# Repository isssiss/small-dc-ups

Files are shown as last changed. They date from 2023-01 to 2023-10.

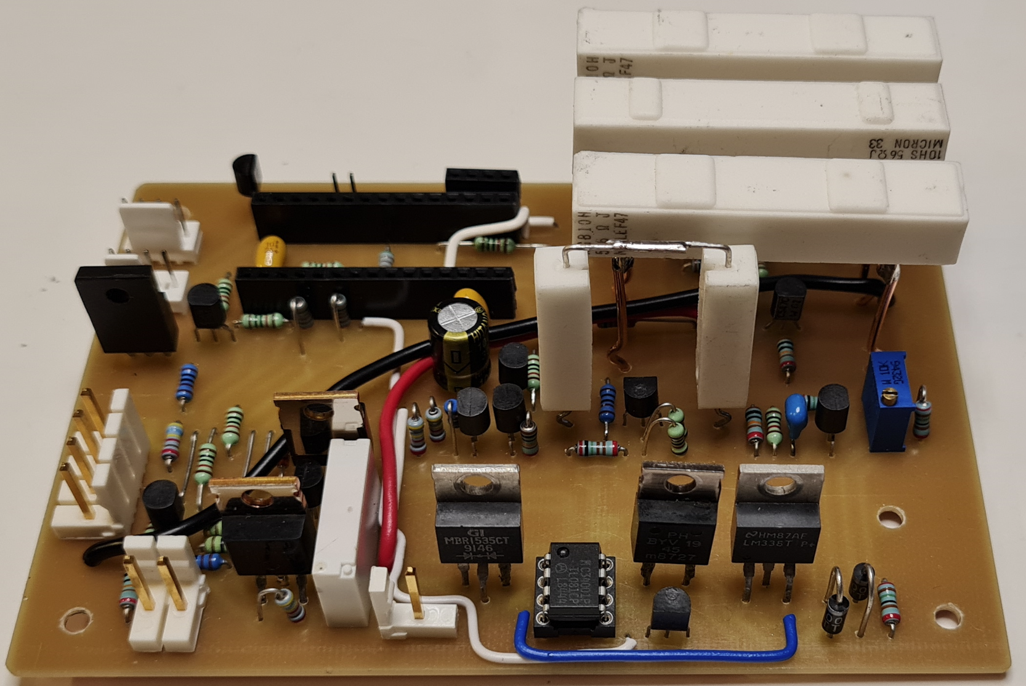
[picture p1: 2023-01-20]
controller/components.png

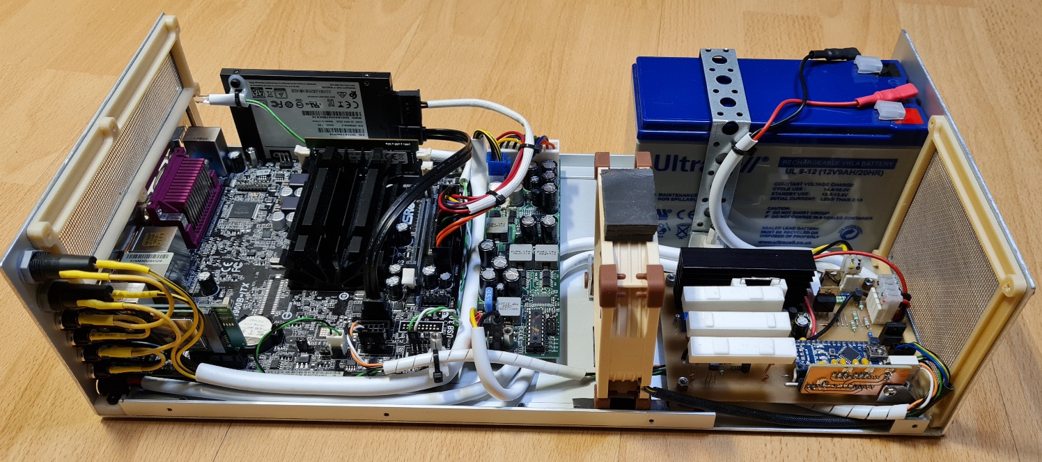
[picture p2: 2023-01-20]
finished.jpg

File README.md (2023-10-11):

# Small DC UPS for Home Assistant/Frigatenvr project

This is designed to power Asrock J1900M-ITX board with a PicoPSU automotive power supply with an input voltage 8...36V.
Mains power is provided by a laptop power supply with 19.5V output.

Backup battery is a 12V 9Ah lead acid gel battery (Ultracell UL-9-12).

Charger is a traditional standby current and voltage limited linear model.

Can be used with standard Network UPS Tools (NUT) with a blazer_ser driver and Megatec ascii protocol.

NOTE: I made only one pcb and the first version had an error. The error is corrected only in the schematic and v2 pcb image.

### Warning:

The output switch IRF9530 burned after a few months in use. Both IRF9530 were changed to IRF4905 which has much lower internal resistance and higher current rating. Zener diodes were also added in parallel of every fets 47k pullup resistor to limit the gate voltage to about 13V (2x 6.2V zeners in series).

Arduino LM340 voltage regulator is changed to a TSR 1-2540 dc converter because the original will run quite warm with 20V input.

Probably still contains errors and bugs.

I'm not responsible of any possible damage caused by any content stored here.

Use at your own risk, you have been warned.

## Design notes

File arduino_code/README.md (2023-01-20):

# Small-dc-ups Arduino code

I used an Arduino nano 5V 16MHz Atmega328P card.

* dc_ups.ino

  Main program

* ups_adc.h, ups_adc.cpp
    
  ADC helper code

* ups_util.h, ups_util.cpp

  Number formatting helpers

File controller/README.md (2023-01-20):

# Small DC UPS controller

UPS controller board

There are some old and various components because I designed this with the components I already had.

NOTE: Only one board was made and the schematic had an error. Fix can be seen in copper_side.png and it is fixed only in the schematic and pcb_v2_from_top.png.
Some components need to be installed on copper side.

In pcb_v2_from_top.png red lines are on pcb copper side, grey is ground (plane on copper side after milling the traces) and blue is  jumpers (board component side).

* ups_1_4_source.pdf

  Power connections and output current measurement.
  Use low dropout diode for D1 (MBR1535CT).

* ups_2_4_charge.pdf

  Battery charger and charge current measurement.
  Charge current can be adjusted with R17/R18.
  Adjust R23 to correct charge end voltage without a connected battery. Measure at D8 cathode.
  See components.png for R14-R15 placement.

* ups_3_4_control.pdf

  Arduino and fan control.

* ups_4_4_testload.pdf

  Battery test load.
  See components.png for R47-R49 placement.

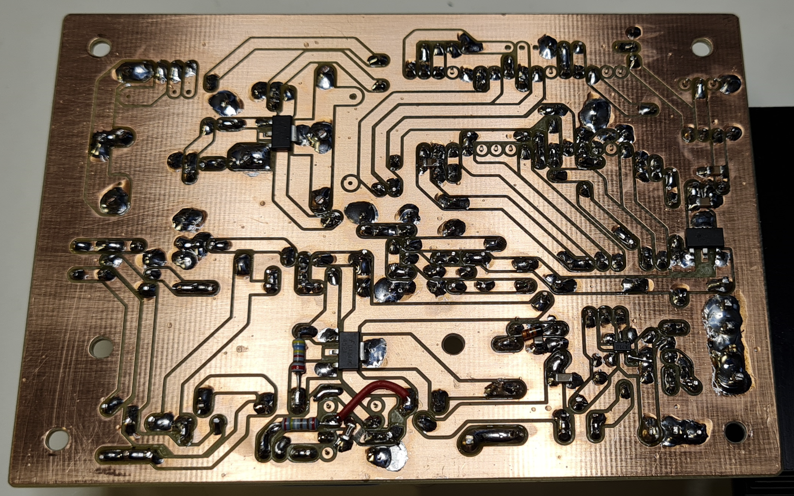
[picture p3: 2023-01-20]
controller/copper_side.png

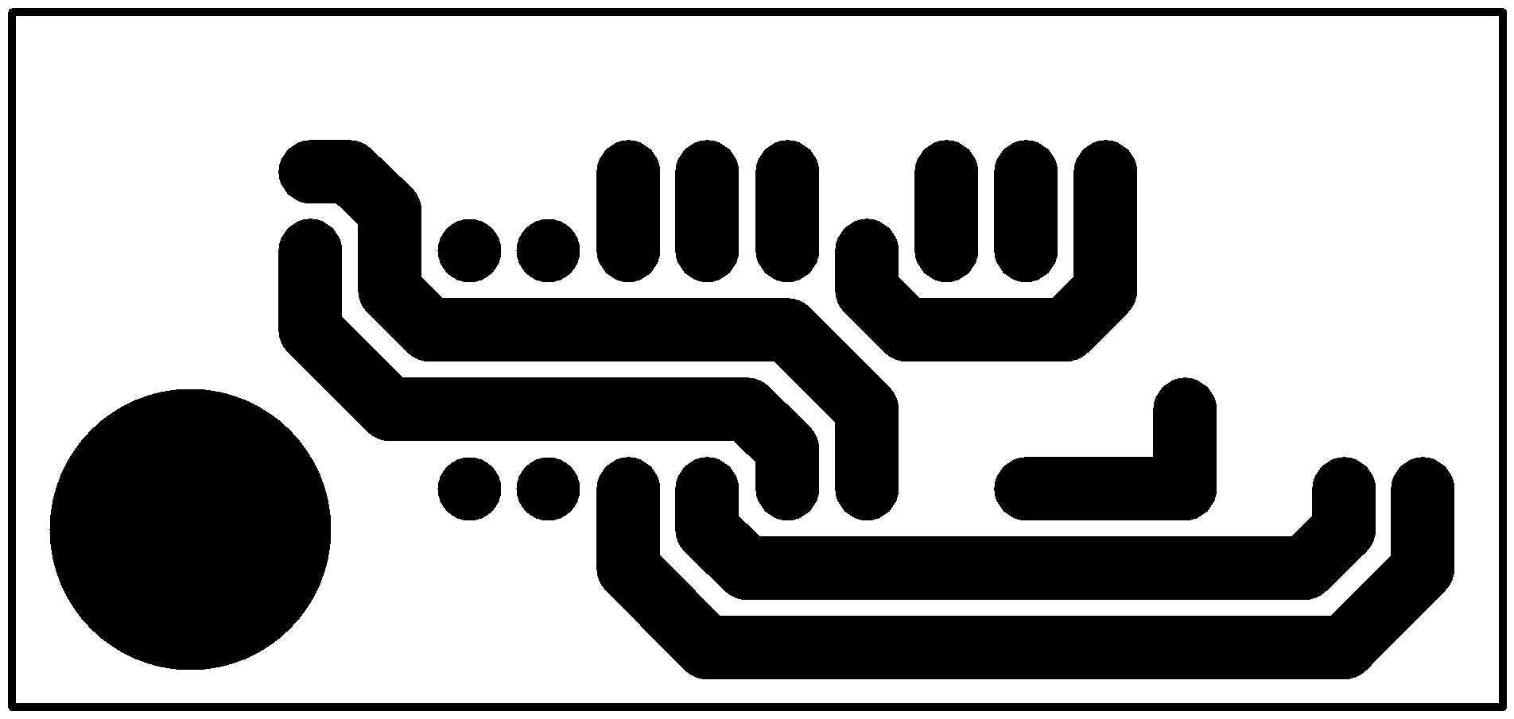
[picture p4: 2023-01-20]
serial/pcb files/SERIAL.BOTTOM.bmp

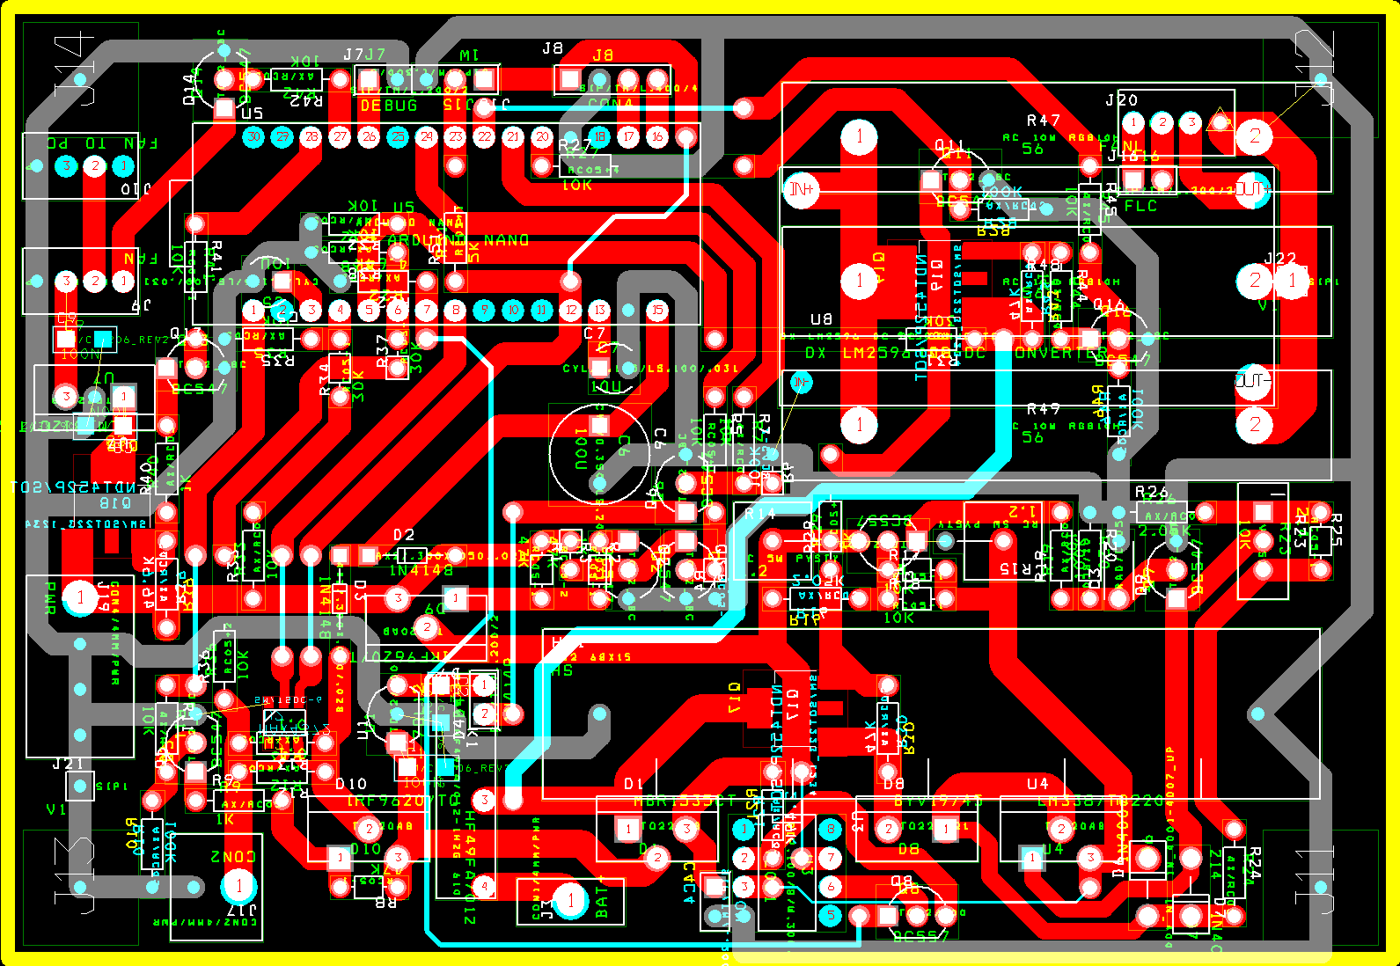
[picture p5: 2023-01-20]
controller/pcb_v2_from_top.png

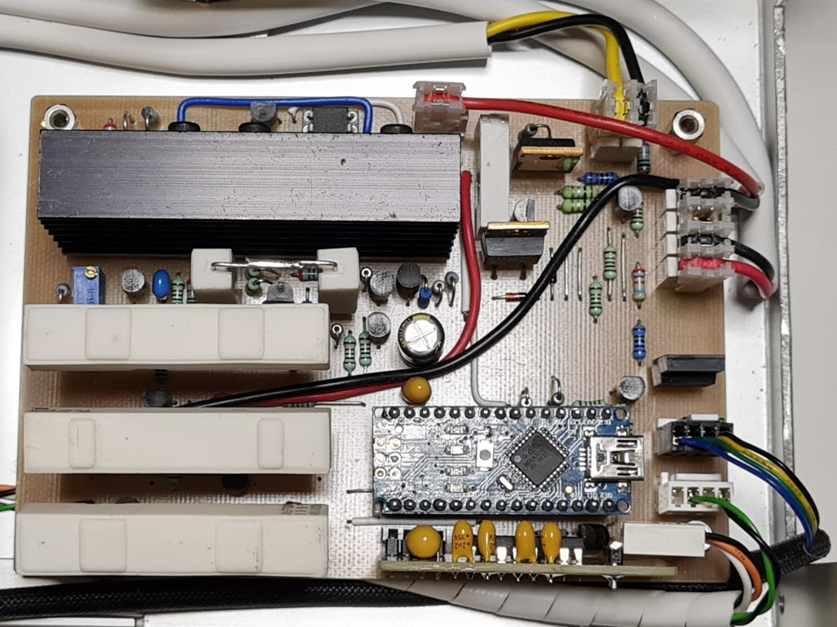
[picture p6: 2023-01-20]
controller/finished.png

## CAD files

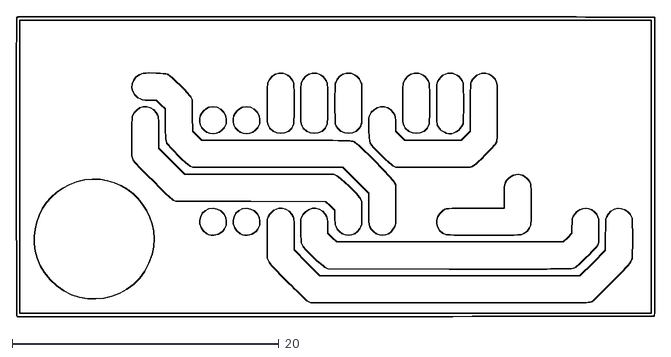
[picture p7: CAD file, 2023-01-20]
serial/pcb files/SERIAL.BOTTOM.dxf
47.9 x 22.5

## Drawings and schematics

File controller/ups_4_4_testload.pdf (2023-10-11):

# Optional, not used in v1

## J20FL

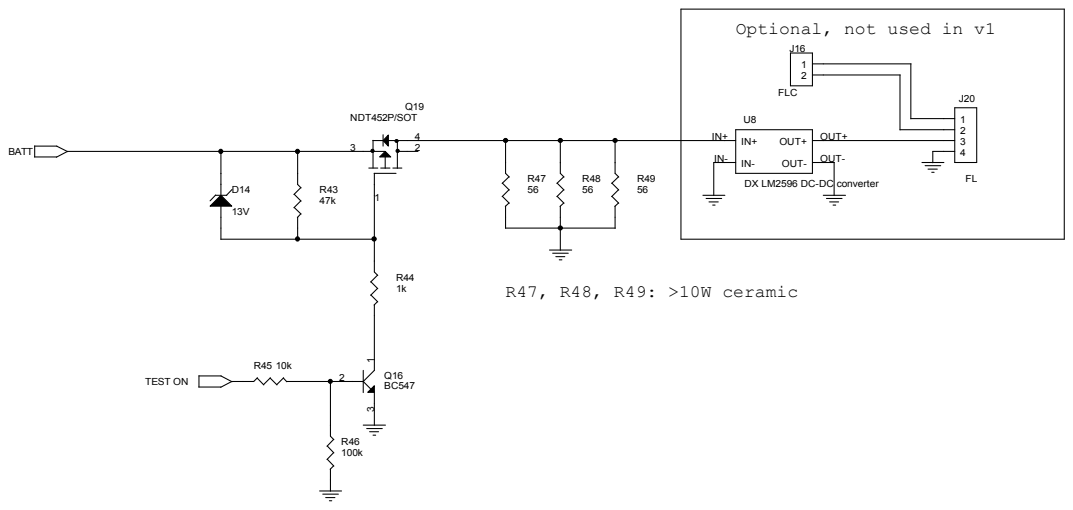
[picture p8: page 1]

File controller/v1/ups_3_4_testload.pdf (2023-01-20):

# Optional, not used in v1

## J20FL

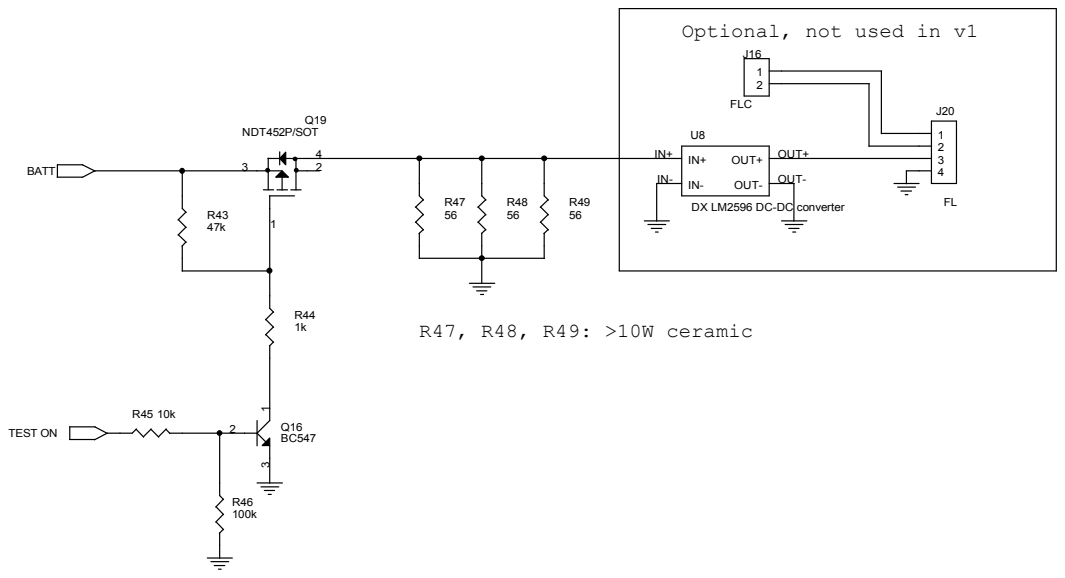
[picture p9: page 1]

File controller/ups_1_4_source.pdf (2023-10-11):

# 1N4148 U2 MAX4372

R12 0.1 R10

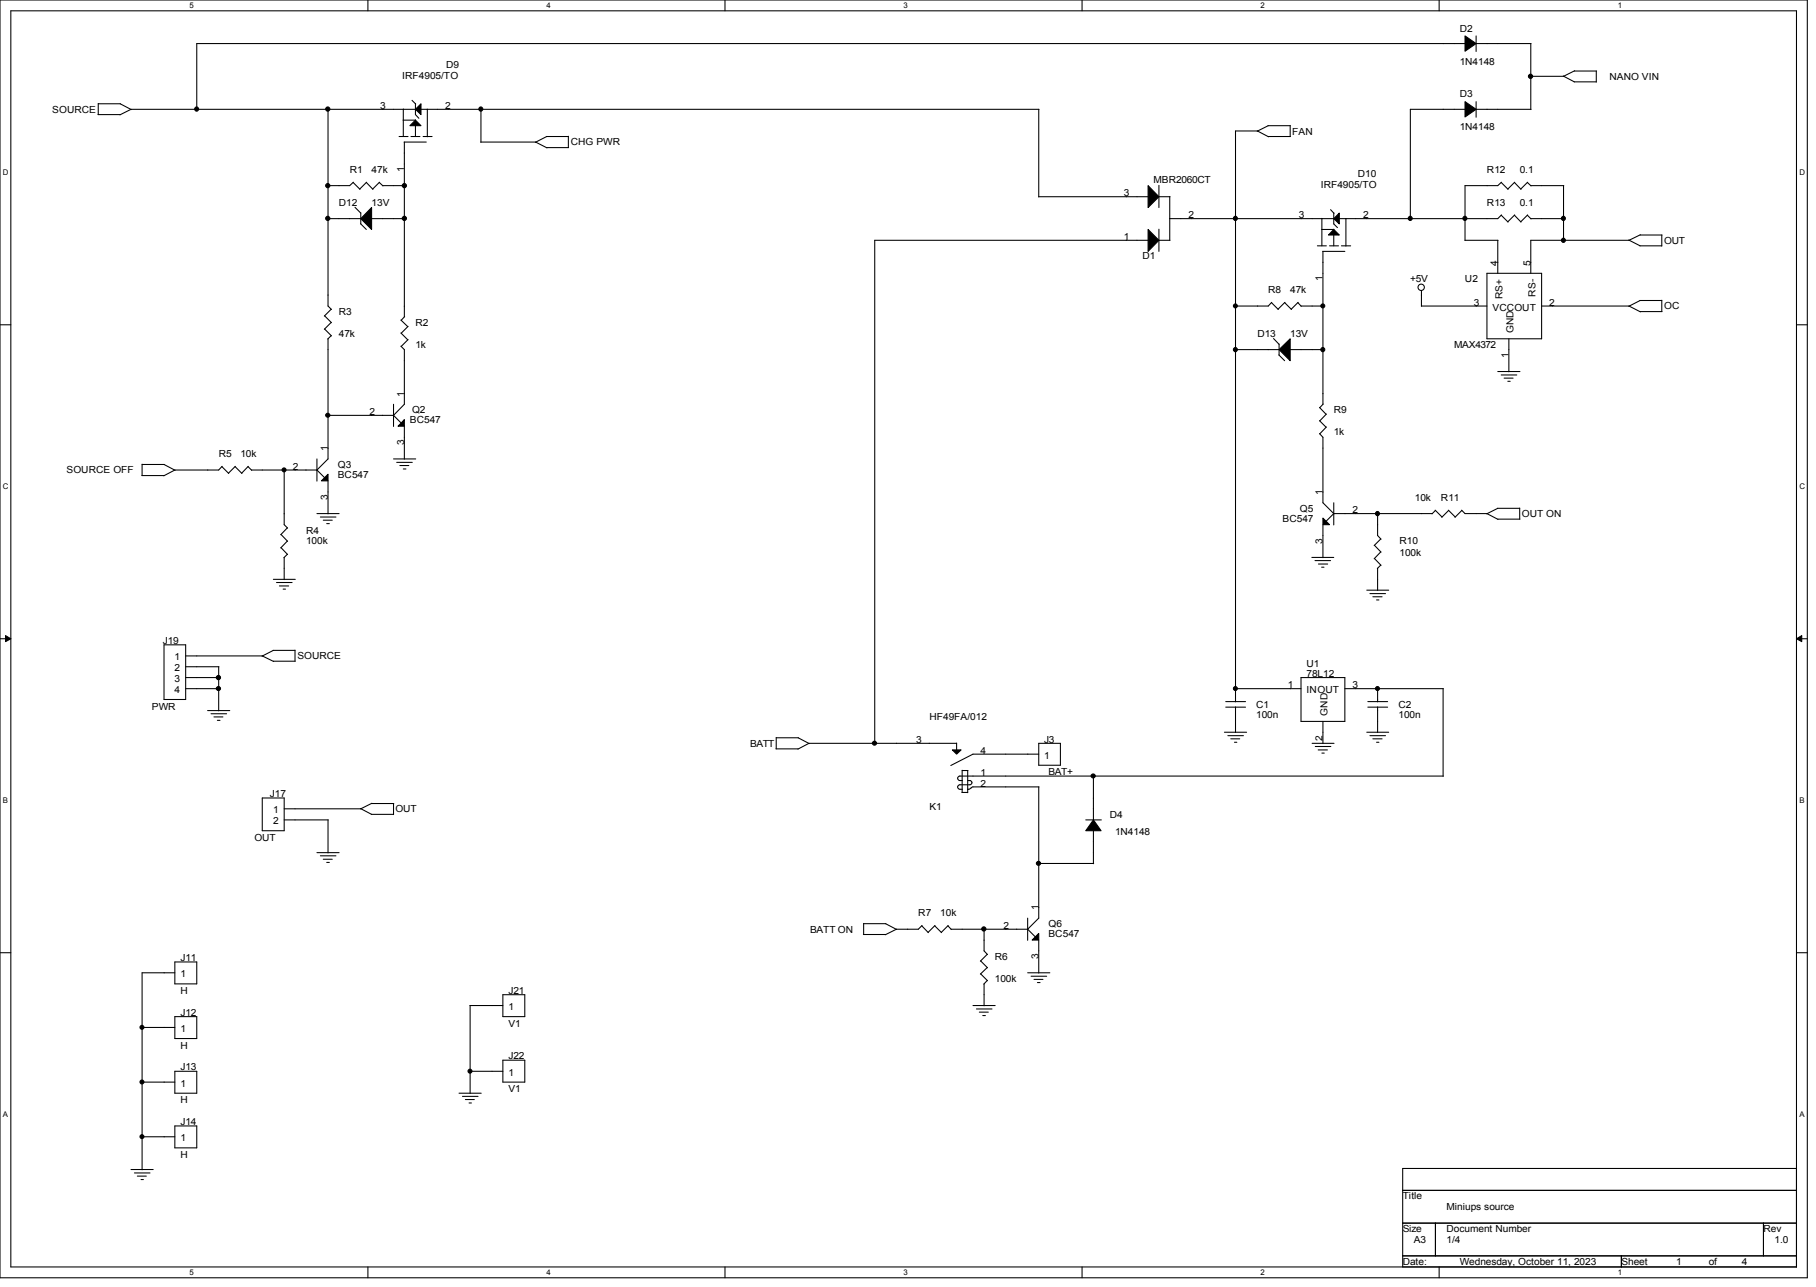
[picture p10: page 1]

OUT OC OUT ON

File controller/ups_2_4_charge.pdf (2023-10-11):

# R14, R15: 5W ceramic

# 2 D7

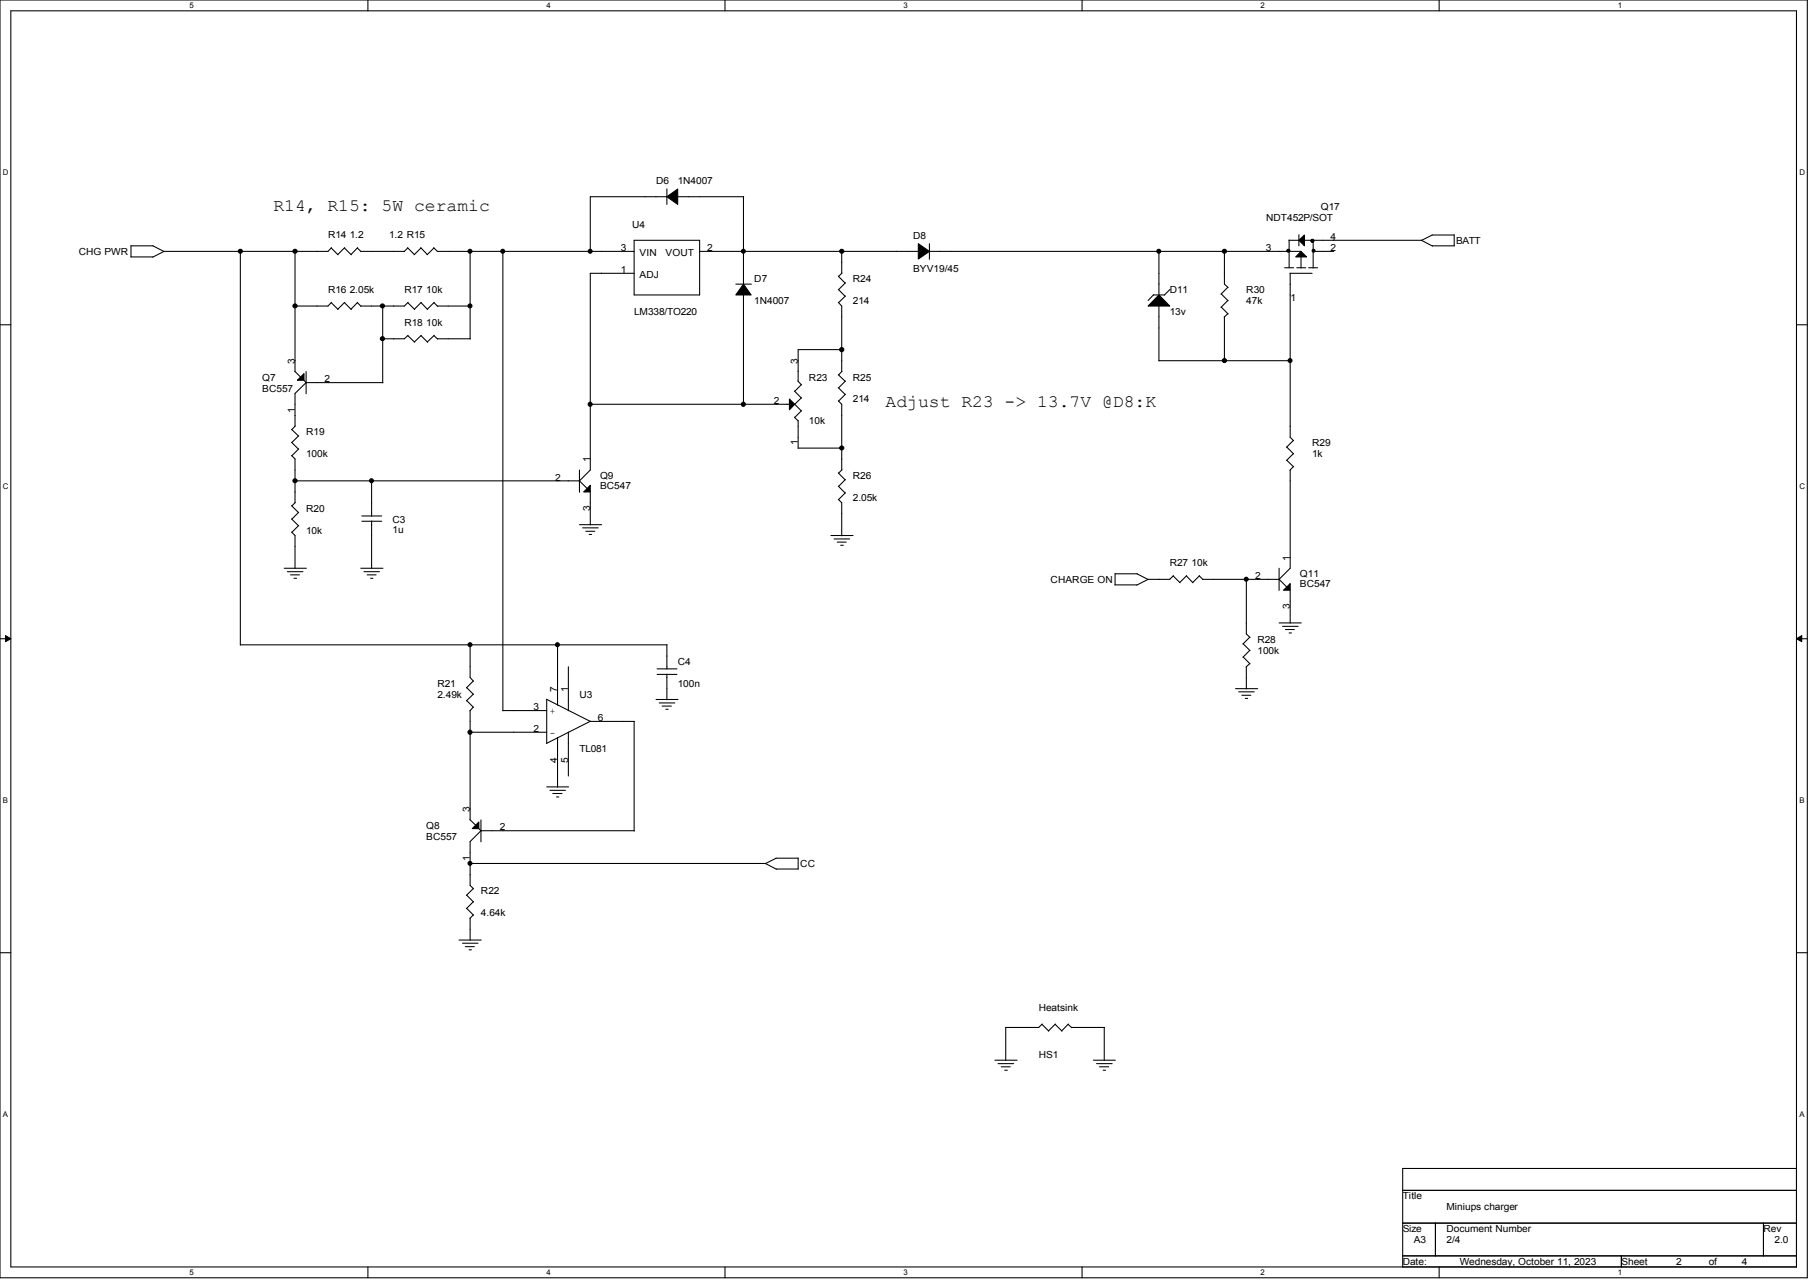
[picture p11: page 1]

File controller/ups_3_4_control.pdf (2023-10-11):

30k R32

30k R35

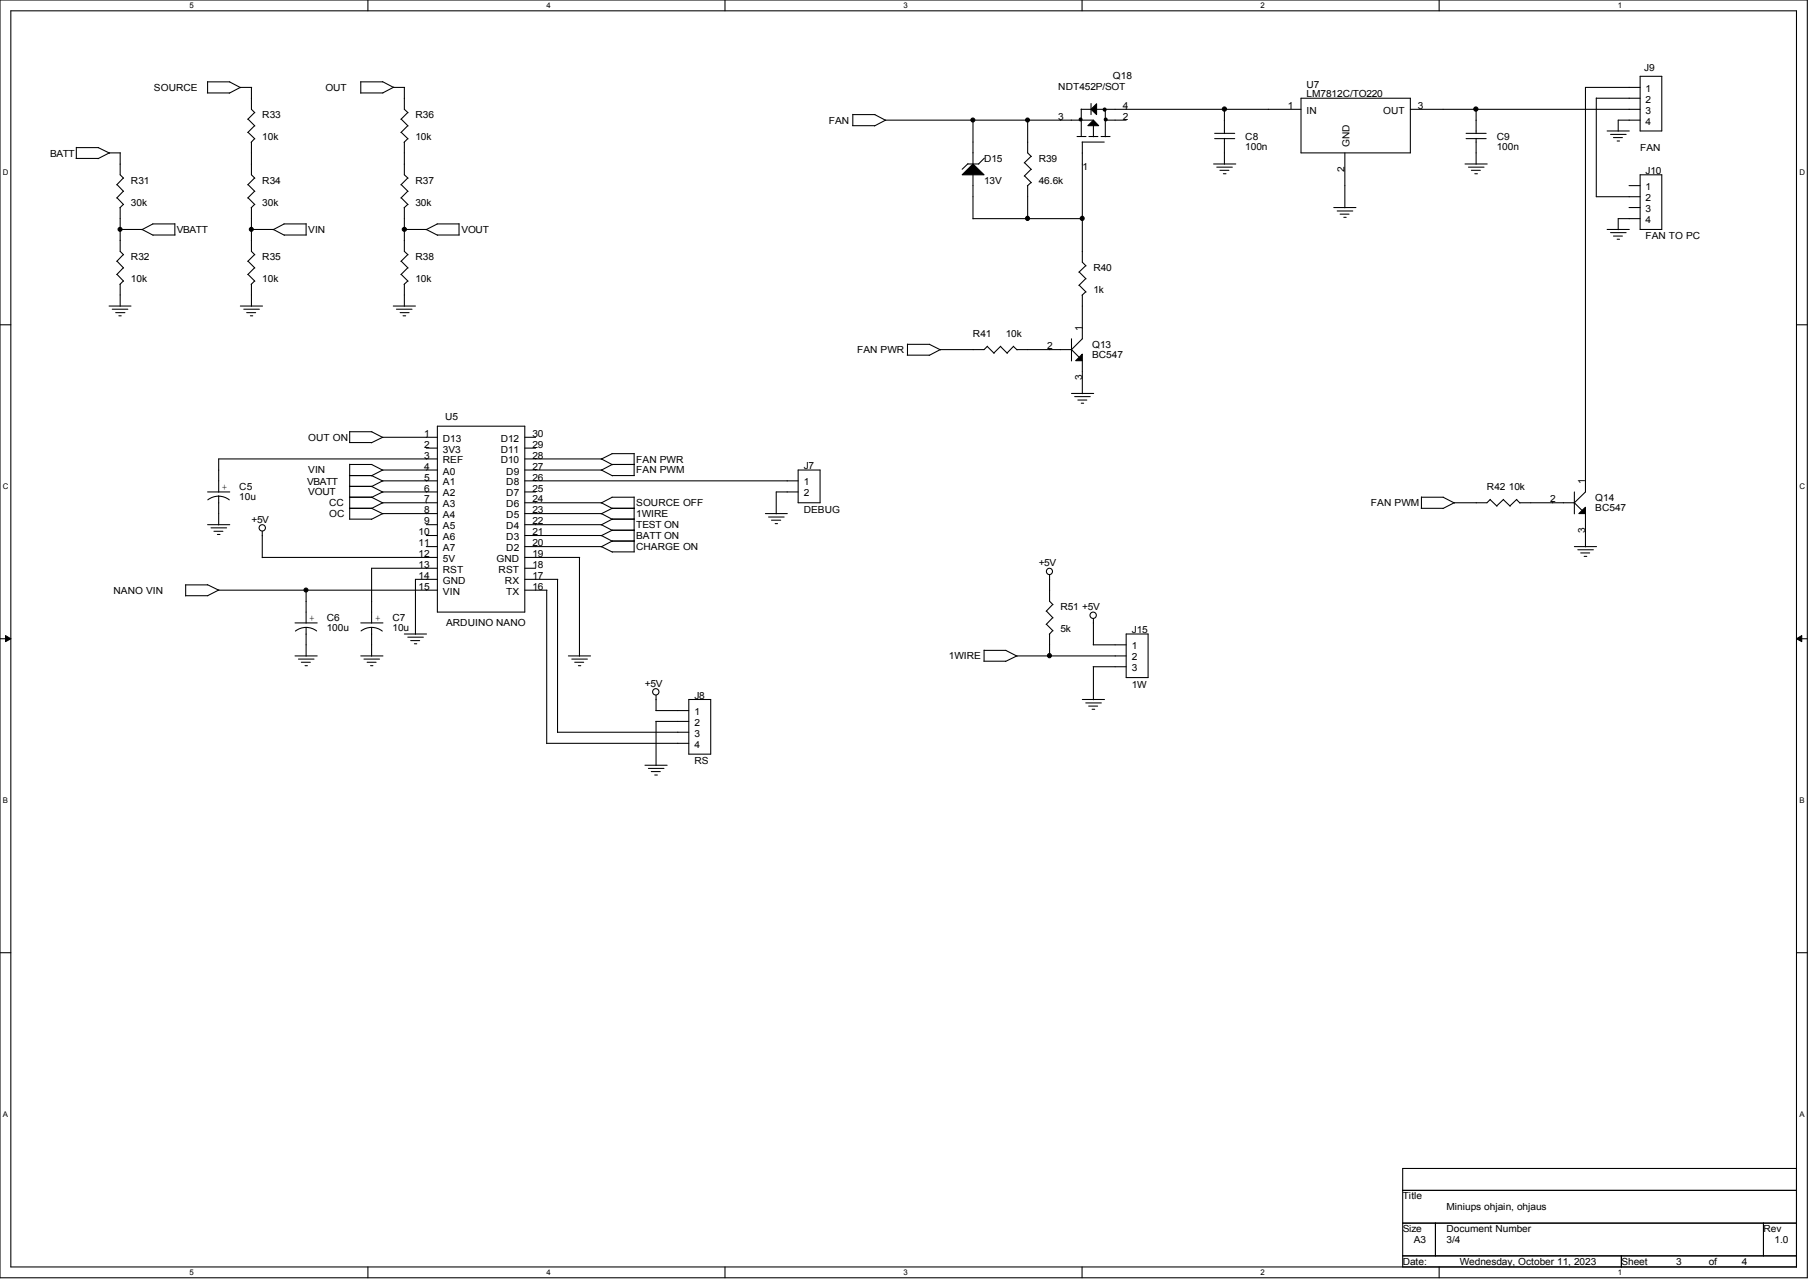
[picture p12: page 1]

BATT ON OUT ON

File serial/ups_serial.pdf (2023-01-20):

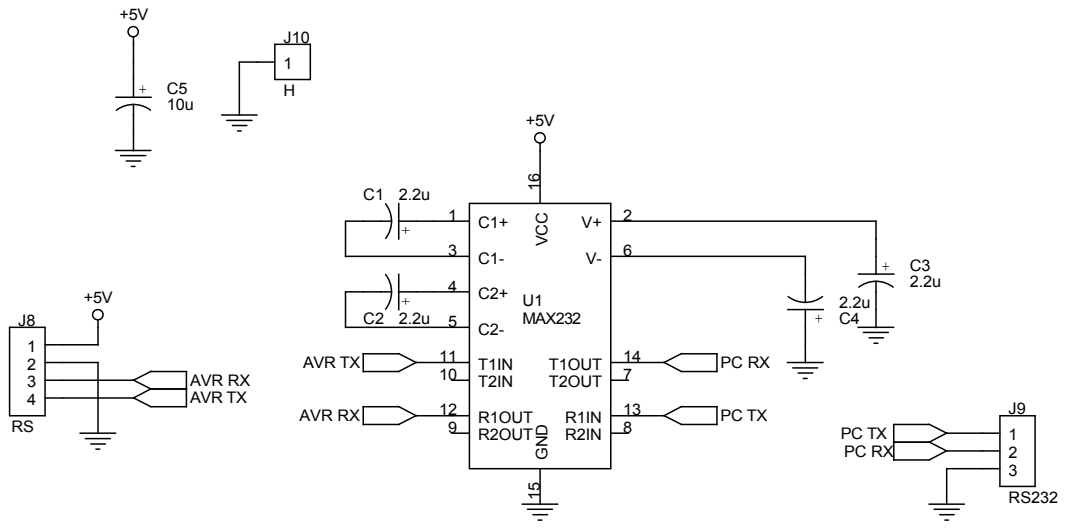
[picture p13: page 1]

Date: Friday, January 20, 2023 | Sheet 1 of 1

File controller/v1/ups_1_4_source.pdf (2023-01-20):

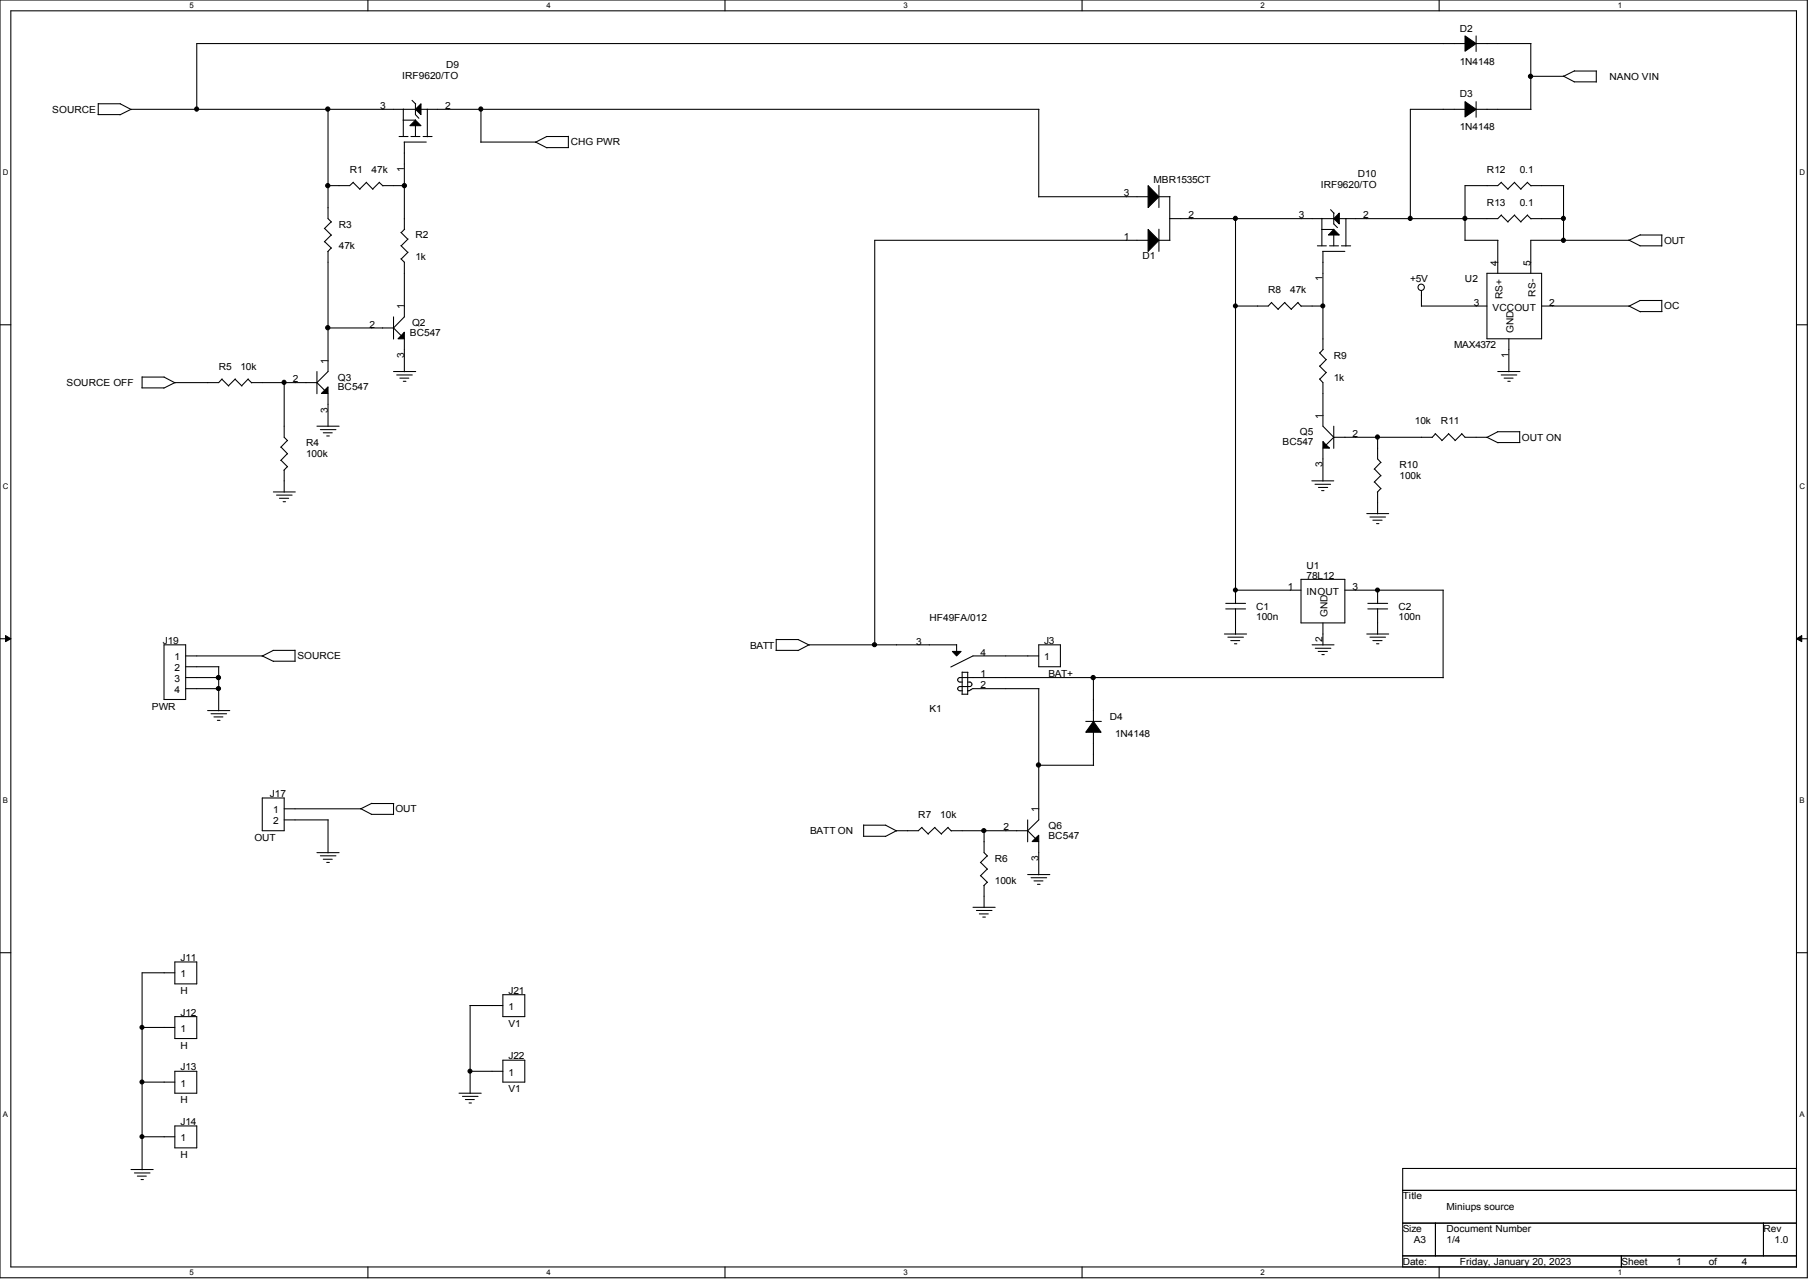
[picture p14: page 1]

OUT OC OUT ON

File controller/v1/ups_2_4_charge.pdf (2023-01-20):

# R14, R15: 5W ceramic

# 4 R27 10k

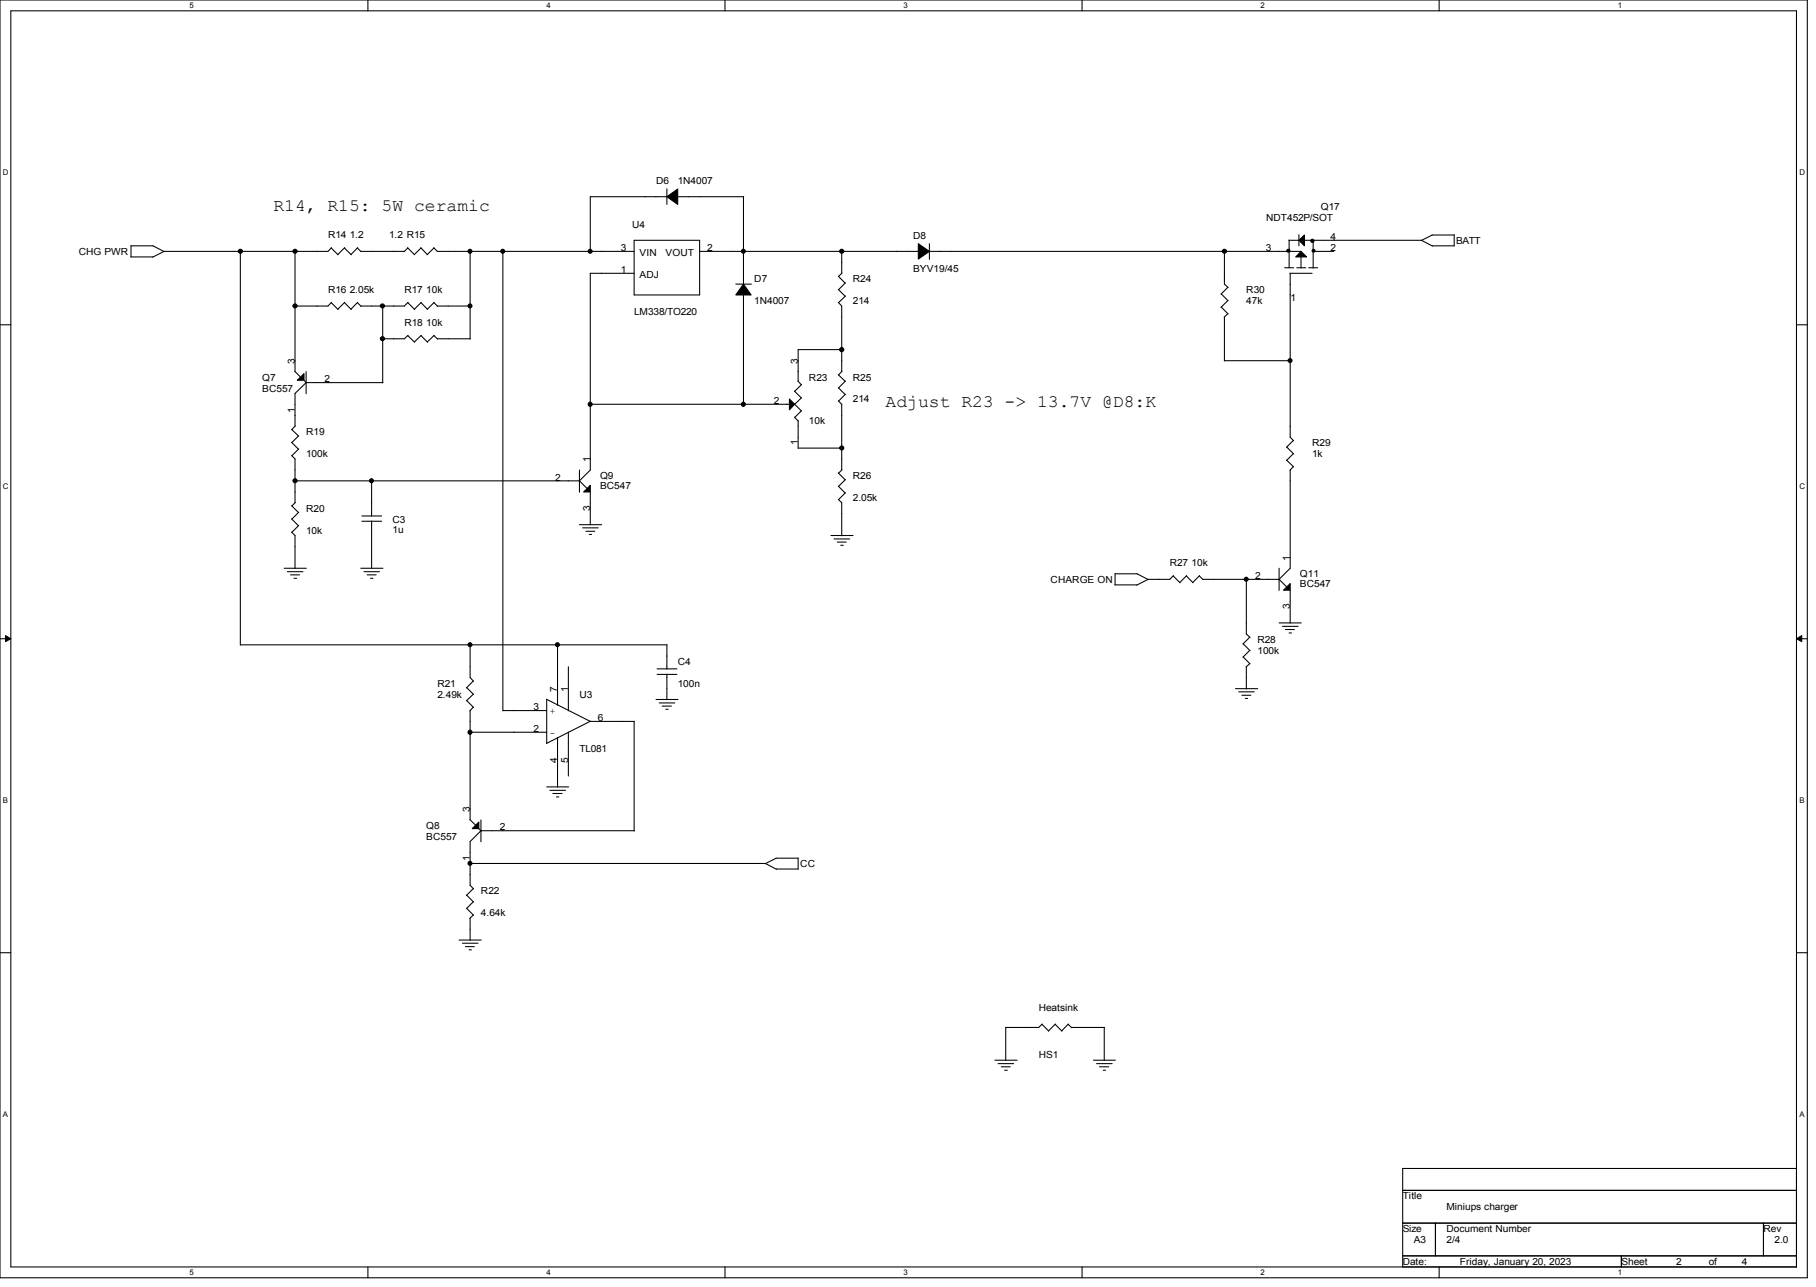
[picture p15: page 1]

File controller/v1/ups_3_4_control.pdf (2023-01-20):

30k R32

30k R35

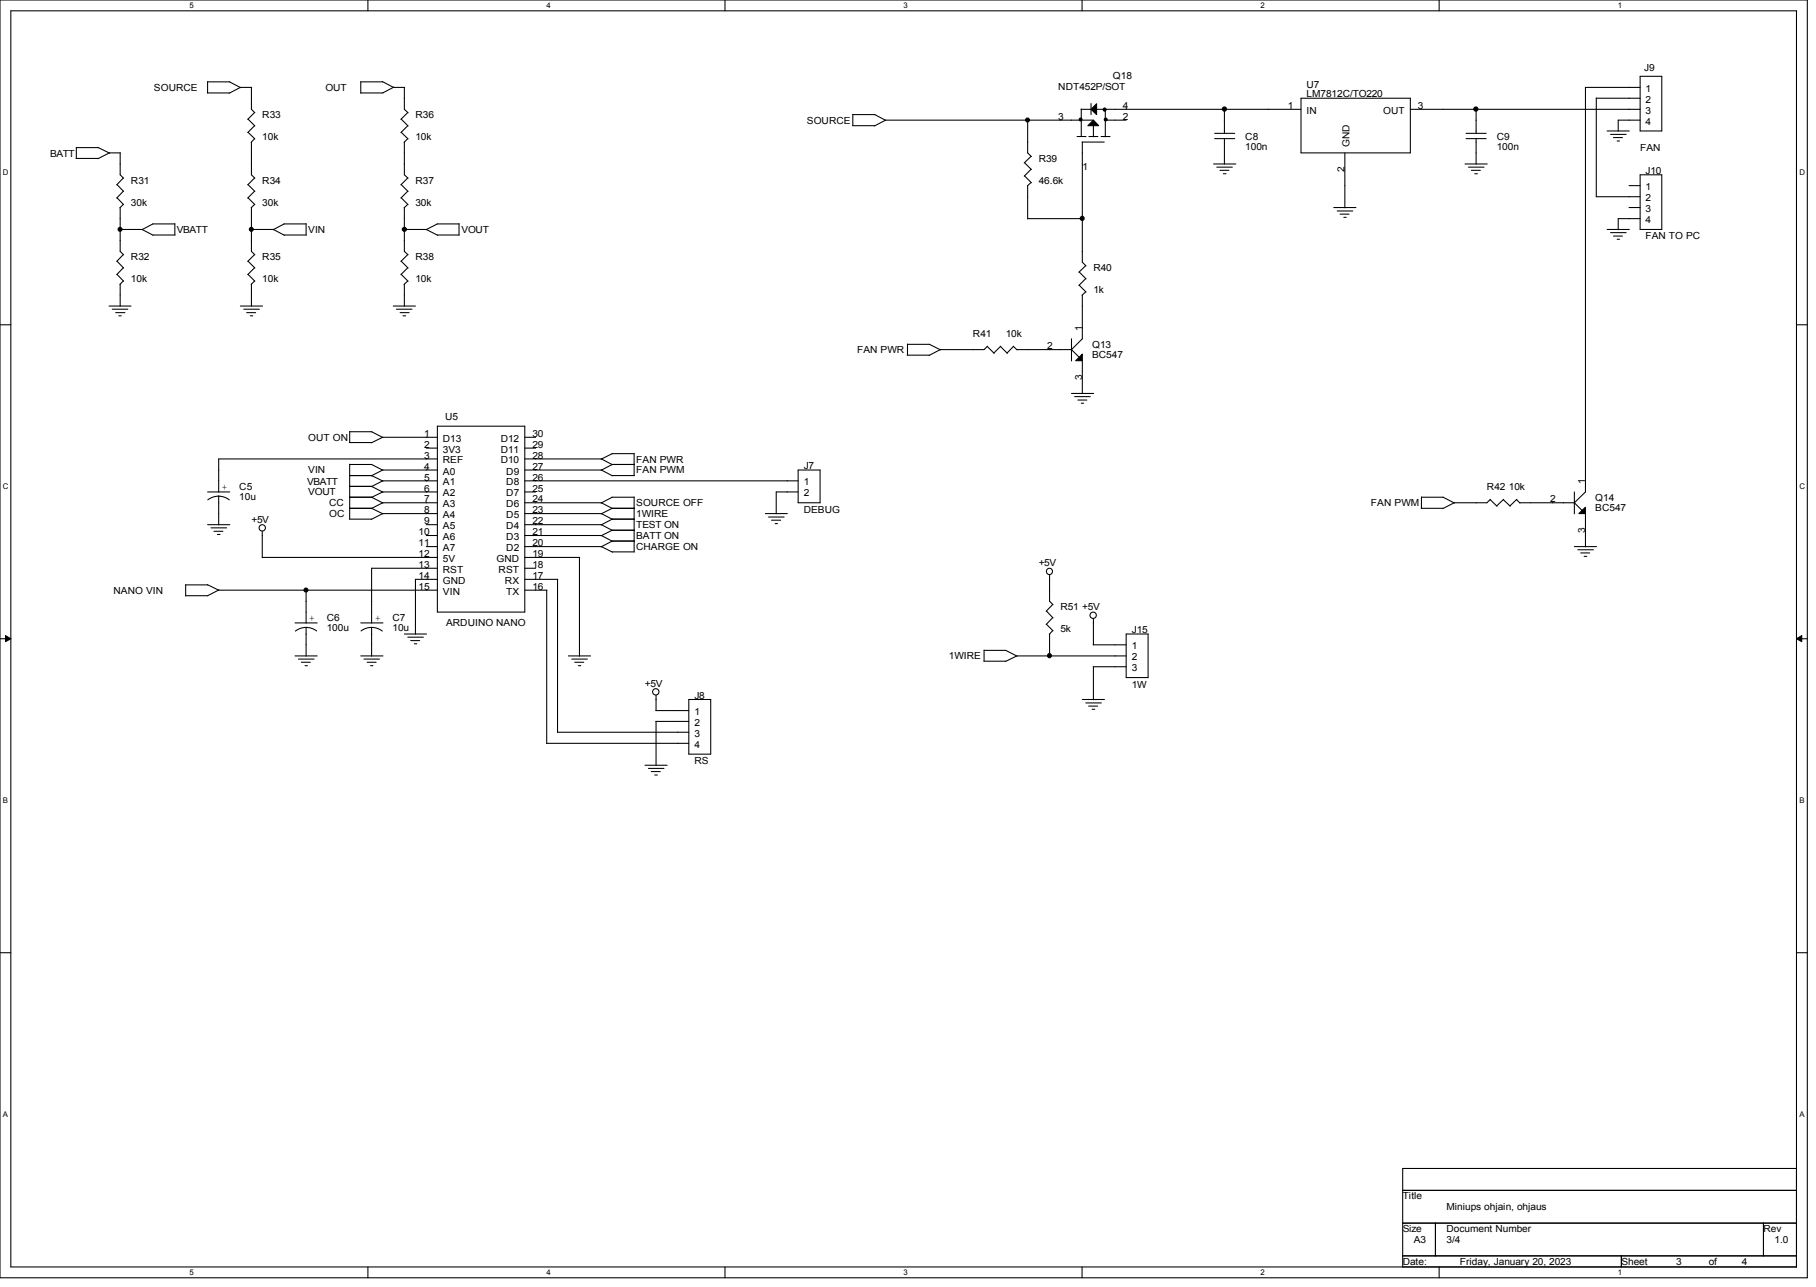
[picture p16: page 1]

BATT ON OUT ON

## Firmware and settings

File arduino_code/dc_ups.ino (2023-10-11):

/*
 Name:		dc_ups.ino
 Created:	2022-10-10
 Author:	ISS
*/



#include <OneWire.h>
#include <DallasTemperature.h>
#include "ups_adc.h"
#include "ups_util.h"
#include <stdint.h>


/*
// Settings

	wiva1.002		set input_voltage_adjust   [multiplier] (-10.0 ... 10.0)
	wbva1.0085		set battery_voltage_adjust [multiplier] (-10.0 ... 10.0)
	wova1.0			set output_voltage_adjust  [multiplier] (-10.0 ... 10.0)
	wcca1.05		set charge_current_adjust  [multiplier] (-10.0 ... 10.0)
	woca1.028		set output_current_adjust  [multiplier] (-10.0 ... 10.0)

	wbmv13.7		set battery_max_voltage [V] battery full voltage with charge (0.0 ... 15.0)
	wbfv12.7		set battery_full_voltage [V] battery full voltage without charge (0.0 ... 15.0)
	wblv11.7		set battery_low_voltage [V] battery empty voltage (0.0 ... 15.0)
	wbbv10.5		set battery_bad_voltage [V] battery too low voltage (0.0 ... 15.0)
	wbmc4.0			set battery_max_capacity [Ah] battary capacity (0.0 ... 9.0)
	wbcm1440		set battery_max_charge_mins [minutes] = 24h   max charge time (0 ... 4320)
	wbbm360			set battery_max_bad_mins [minutes] = 6h  max battery too low time (0 ... 1440)
	wblm720			set battery_max_low_mins [minutes] = 12h max battery low time (0 ... 1440)
	wbdt2022-01-10		set battery_date [yyyy-mm-dd]       battery change date (string, 10 chars)
	wobm120         	set on_battery_max_time_mins [minutes] = 2h  max run time on battery (0 ... 540)
	wmoc4.0			set max_output_current [A]   max output current (1.0 ... 5.0)
 
	wati1440		set auto_test_interval_mins [minutes] = 24h    automatic test interval (>= 0)
	watd0			set auto_test_duration_mins [minutes], 0 = 30seconds, >0 minutes   automatic test duration (0 ... 60)
	wtmi10			set measure_interval_secs [seconds]   temperature measure interval (0 ... 65535)
	wthl30.0		set temperature_high_limit [C degrees]   temperature high limit (25.0 ... 60.0)

	wfmi40			set fan_min_pwm [%]    fan min speed (0 ... 100)
	wfma80			set fan_max_pwm [%]    fan max speed (0 ... 100)

	wdbg1			set debug_override [0 = normal, 1 = debug messages on]    debug messages



*/


// Vakiot
#define SERIAL_SPEED					2400
#define FAN_PWM_TOP						320

#define INPUT_VOLTAGE_LOW				16.0
#define INPUT_VOLTAGE_OK				16.1
#define BATTERY_TEST_CURRENT			680.0
#define MAX_CHARGE_CURRENT				1000.0

#define CHARGE_CURRENT_FULL				20.0
#define CHARGE_CURRENT_STOP_FAN			200.0
#define CHARGE_CURRENT_START			200.0
#define CHARGE_CURRENT_END				100.0
#define CHARGE_TIME_START_FAN			30000UL
#define CHARGE_TIME_ADJUST_FAN			35000UL
#define TEST_TIME_START_FAN				30000UL		// probably a bit too long... maybe 20seconds
#define BATTERY_TEST_TIME_CONNECTED		30000UL
#define BATTERY_TEST_TIME_DISCONNECTED	600000UL

// Output state
#define OUTPUT_STATE_OFF				0
#define OUTPUT_STATE_ON_DELAY			1
#define OUTPUT_STATE_ON					2



// EEPROM
float    EEMEM ee_battery_max_voltage 			= 13.7;			// Max battery voltage with charge (V)	[EEPROM]
float    EEMEM ee_battery_full_voltage 			= 12.7;			// Max battery voltage without charge (V)	[EEPROM]
float    EEMEM ee_battery_low_voltage 			= 11.5;			// Battery low voltage (V)	[EEPROM]
float    EEMEM ee_battery_bad_voltage 			= 10.5;			// Battery dead voltage (V)	[EEPROM]
float    EEMEM ee_battery_max_capacity 			= 3.6;			// Max usable battery capacity (Ah)	[EEPROM]
float    EEMEM ee_max_output_current 			= 4;			// Max output current (A)	[EEPROM]
uint16_t EEMEM ee_auto_test_interval_mins 		= 1440;			// Automatic test (long) interval (minute)	[EEPROM]
uint8_t  EEMEM ee_auto_test_duration_mins 		= 0;			// Automatic test duration (minute), 0 => 10 sek, 255 => akku tyhjäksi	[EEPROM]
uint16_t EEMEM ee_temp_measure_interval_secs 	= 10;			// Temperature measure interval (second)	[EEPROM]
char     EEMEM ee_battery_date[11] 				= "2022-01-10";	// Battery install date (YYYY-MM-DD)	[EEPROM]
float    EEMEM ee_input_voltage_adjust 			= 0.0;			// Adjustment multiplier	[EEPROM]
float    EEMEM ee_battery_voltage_adjust 		= 0.0;			// Adjustment multiplier	[EEPROM]
float    EEMEM ee_output_voltage_adjust 		= 0.0;			// Adjustment multiplier	[EEPROM]
float    EEMEM ee_charge_current_adjust 		= 0.0;			// Adjustment multiplier	[EEPROM]
float    EEMEM ee_output_current_adjust 		= 0.0;			// Adjustment multiplier	[EEPROM]
uint8_t  EEMEM ee_debug_override 				= 1;			// Force debug mode	[EEPROM]
uint8_t  EEMEM ee_fan_min_pwm 					= 30;			// Fan min speed	[EEPROM]
uint8_t  EEMEM ee_fan_max_pwm 					= 100;			// Fan max speed	[EEPROM]
uint16_t EEMEM ee_battery_max_charge_mins		= 1440;			// Max charge duration (longer => battery dead)	[EEPROM]
uint16_t EEMEM ee_battery_max_low_mins 			= 360;			// Max battery low duration (longer => battery dead)	[EEPROM]
uint16_t EEMEM ee_battery_max_bad_mins 			= 720;			// Max battery too low duration (longer => battery dead)	[EEPROM]
uint16_t EEMEM ee_on_battery_max_time_mins 		= 120;			// Max run time on battery (2h). If longer utility loss => treat as battery low [EEPROM]
float    EEMEM ee_temperature_high_limit 		= 30.0;			// Temperature limit, start fan if higher	[EEPROM]




// arvot
float    battery_max_voltage        = 0.0;
float    battery_full_voltage       = 0.0;
float    battery_low_voltage        = 0.0;
float    battery_bad_voltage        = 0.0;
float    battery_max_capacity       = 0.0;
float    max_output_current         = 0.0;
uint16_t auto_test_interval_mins    = 0;
uint8_t  auto_test_duration_mins    = 0;
uint16_t temp_measure_interval_secs = 0;
char     battery_date[11]           = "";
float    input_voltage_adjust       = 0.0;
float    battery_voltage_adjust     = 0.0;
float    output_voltage_adjust      = 0.0;
float    charge_current_adjust      = 0.0;
float    output_current_adjust      = 0.0;
uint8_t  debug_override             = 0;
uint8_t  fan_min_pwm                = 0;
uint8_t  fan_max_pwm                = 0;
uint16_t battery_max_charge_mins    = 0;
uint16_t battery_max_low_mins       = 0;
uint16_t battery_max_bad_mins       = 0;
uint16_t on_battery_max_time_mins   = 0;
float    temperature_high_limit     = 0.0;


uint8_t fan_pwm = 0;			// Fan speed
char buf[16];					// Temporary buffer



// tila
uint8_t is_debug_mode    = 0;	// Debug mode
uint8_t output_state     = 0;	// Output state
uint8_t source_on        = 0;	// Utility on
uint8_t charge_on        = 0;	// Charge on
uint8_t battery_on       = 0;	// Battery on
uint8_t output_on        = 0;	// Output on
uint8_t fan_on           = 0;	// Fan output state
uint8_t fan_on_test      = 0;	// Fan on during test
uint8_t fan_on_charge    = 0;	// Fan on during charge
uint8_t fan_on_temp      = 0;	// Fan on with temperature
uint8_t battery_fail     = 0;	// Battery dead
uint8_t utility_fail     = 0;	// Q1 status
uint8_t battery_low      = 0;	// Q1 status
uint8_t battery_bad      = 0;	// Battery too low
uint8_t ups_fail         = 0;	// Q1 status
uint8_t test_in_progress = 0;	// Q1 status
uint8_t shutdown_active  = 0;	// Q1 status



// mittaukset
float input_voltage   = 0.0;	// Input voltage
float battery_voltage = 0.0;	// Battery voltage
float charge_current  = 0.0;	// Charge current
float output_voltage  = 0.0;	// Output voltage
float output_current  = 0.0;	// Output current
float temperature     = 0.0;	// Temperature

// ajat
uint16_t battery_runtime_mins   = 0.0;			// Run time on battery (minutes)
uint8_t  battery_charge_percent = 0;			// Battery charge level (%)
uint16_t startup_delay_secs     = 10;			// Startup delay (seconds)
uint16_t shutdown_delay_secs    = 0;			// Shutdown delay (seconds)

unsigned long startup_start_time        = 0;	// Start timestamp
unsigned long shutdown_start_time       = 0;	// Shutdown start timestamp
unsigned long last_short_auto_test_time = 0;	// Last automatic test (short) timestamp
unsigned long last_long_auto_test_time  = 0;	// Last automatic test (long) timestamp
unsigned long last_measure_time         = 0;	// Last temperature measurement timestamp


unsigned long test_start_time           = 0;	// Test start timestamp
uint16_t      test_run_time_secs        = 0;	// Test time (seconds)

unsigned long battery_charge_start_time = 0;	// Charge start timestamp
uint16_t      battery_charge_time_mins  = 0;	// Charge suration (minutes)

unsigned long battery_low_start_time    = 0;	// Battery low start timestamp
uint16_t      battery_low_time_mins     = 0;	// Battery low duration (minutes)

unsigned long battery_bad_start_time    = 0;	// Battery too low start timestamp
uint16_t      battery_bad_time_mins     = 0;	// Battery too low duration (minutes)

unsigned long on_battery_start_time     = 0;	// On battery start timestamp
uint16_t      on_battery_time_mins      = 0;	// On battery duration (minutes)

unsigned long last_battery_check_time   = 0;	// Last battery check timestamp





// PB5 (D13) => OUT ON
#define OUTPUT_ON()     (PORTB |= (1 << PB5))
#define OUTPUT_OFF()	(PORTB &= ~(1 << PB5))

// PB4 (D12)

// PB3 (D11)

// PB2 (D10) => FAN PWR
#define FAN_ON()		(PORTB |= (1 << PB2));  fan_on = 1
#define FAN_OFF()		(PORTB &= ~(1 << PB2)); fan_on = 0

// PB1 (D9) => FAN PWM (OC1A)

// PB0 (D8) => SETUP MODE INPUT
#define IS_DEBUG_INPUT()	((PINB & (1 << PB0)) > 0 ? 0 : 1)

// PD7 (D7)

// PD6 (D6) => SOURCE OFF
#define SOURCE_ON()     (PORTD &= ~(1 << PD6)); source_on = 1
#define SOURCE_OFF()	(PORTD |= (1 << PD6));  source_on = 0

// PD5 (D5) => 1-WIRE ?
#define  ow_pin  5

// PD4 (D4) => TESTLOAD ON
#define TESTLOAD_ON()   (PORTD |= (1 << PD4))
#define TESTLOAD_OFF()	(PORTD &= ~(1 << PD4))

// PD3 (D3) => BATT ON
#define BATTERY_ON()    (PORTD |= (1 << PD3));  battery_on = 1
#define BATTERY_OFF()	(PORTD &= ~(1 << PD3)); battery_on = 0

// PD2 (D2 ) => CHARGE ON
#define CHARGE_ON()     (PORTD |= (1 << PD2));  charge_on = 1
#define CHARGE_OFF()	(PORTD &= ~(1 << PD2)); charge_on = 0




// Temperature, 1 kpl DS18B20
OneWire ds = OneWire(ow_pin);
DallasTemperature sensor = DallasTemperature(&ds);

void measure_temperature() {
	DeviceAddress ow_device;
	// Init 1-wire system, resolution = 12bit, wait for conversion
	sensor.begin();
	sensor.setResolution(TEMP_12_BIT);
	sensor.setWaitForConversion(TRUE);
	// Send measure commad for all sensors
	sensor.requestTemperatures();
	if (sensor.getDeviceCount() > 0) {
		sensor.getAddress(ow_device, 0);
		temperature = sensor.getTempC(ow_device);
	}
}




// Fan speed set %,  0 .. 100

uint8_t set_fan_pwm(uint8_t percent, uint8_t ident) {
	if (percent < fan_min_pwm) {
		percent = 0;
	} else if (percent > fan_max_pwm) {
		percent = fan_max_pwm;
	}
	//fan_pwm = percent;
	if (is_debug_mode > 0) {
		Serial.print(F("f pwm ")); Serial.print(ident); Serial.print(F(" => ")); Serial.println(percent);
	}
	float v = ((float)FAN_PWM_TOP * ((float)percent / 100.0));
	if (v > (float)FAN_PWM_TOP) {
		v = FAN_PWM_TOP;
	}
	if (v < 0) v = 0;
	OCR1A = (uint16_t)v;
	return(percent);
}



// Measure voltages and currents
void measure_values() {
	battery_voltage = ((float)readADC(ADC_V_BATT) / 1024.0) * 20.0 * battery_voltage_adjust;
	charge_current =  ((float)readADC(ADC_A_CGH)  / 1024.0) * 1050.0 * charge_current_adjust;
	input_voltage =   ((float)readADC(ADC_V_IN)   / 1024.0) * 25.0 * input_voltage_adjust;
	output_voltage =  ((float)readADC(ADC_V_OUT)  / 1024.0) * 25.0 * output_voltage_adjust;
	output_current =  ((float)readADC(ADC_A_OUT)  / 1024.0) * 5000.0 * output_current_adjust;
}





// Start test
void start_test() {
	// 1. Charge off
	CHARGE_OFF();
	// 2. If battery is disconnected, connect
	if (battery_on == 0) {
		BATTERY_ON();
	}
	// 3. delay for relay connect and voltage stabilization
	delay(1000);
	// 4. measure
	measure_values();

	if (is_debug_mode > 0) {
		Serial.print(F("start test BV = ")); Serial.println(battery_voltage, 2);
	}
	// Battery too low, no need to test -> disconnect & fail
	if (battery_voltage < battery_bad_voltage) {
		// 5. Too low -> battery dead. Disconnect
		if (is_debug_mode > 0) {
			Serial.println(F("start test BV B -> fail"));
		}
		battery_bad = 1;
		battery_low = 1;
		battery_fail = 1;
		ups_fail = 1;
		BATTERY_OFF();
	} else {
		// 6. Battery voltage > bad -> run test
		test_in_progress = 1;
		test_start_time = millis();
		TESTLOAD_ON();
	}
}



// Stop test
void stop_test() {
	TESTLOAD_OFF();
	test_in_progress = 0;
	test_start_time = 0;
	if (fan_on_test > 0) {
		fan_on_test = 0;
		fan_pwm = set_fan_pwm(fan_min_pwm, 103);
	}
	CHARGE_ON();
}

// Start shutdown
void start_shutdown() {
	shutdown_active = 1;
	shutdown_start_time = millis();
}

// Cancel shutdown
void cancel_shutdown() {
	shutdown_active = 0; 
	shutdown_start_time = 0;
}

// Output off
void do_shutdown() {
	cancel_shutdown();
	OUTPUT_OFF();
	output_state = OUTPUT_STATE_OFF;
	FAN_OFF();
	fan_pwm = set_fan_pwm(fan_min_pwm, 200);
	fan_on_test = 0;
	fan_on_temp = 0;
	fan_on_charge = 0;
}

// Output on
void do_startup() {
	cancel_shutdown(); 
	stop_test();
	OUTPUT_ON();
	output_state = OUTPUT_STATE_ON;
	startup_start_time = 0;
	fan_pwm = set_fan_pwm(fan_min_pwm, 201);
	FAN_ON();
	fan_on_test = 0;
	fan_on_temp = 0;
	fan_on_charge = 0;
}
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
void loop() {

	unsigned long t = 0;
	double temp_double = 0.0;
	int temp_int = 0;
	long temp_long = 0;

	// Debug mode ?
	is_debug_mode = IS_DEBUG_INPUT();
	if (debug_override == 1) {
		is_debug_mode = 1;
	}

	// Measure
	measure_values();

	// Source
	if (input_voltage < INPUT_VOLTAGE_LOW) {

		// Input voltage low -> stop test, stop charge, start on battery timer

		utility_fail = 1;
		stop_test();	// For safety
		CHARGE_OFF();
		if (on_battery_start_time == 0) {
			on_battery_start_time = millis();
			if (is_debug_mode > 0) {
				Serial.println(F("VIN L -> utl f = 1"));
			}
		} else {
			// Battery run time
			on_battery_time_mins = (millis() - on_battery_start_time) / 60000;
		}
	} else if (input_voltage >= INPUT_VOLTAGE_OK) {

		// Input voltage ok -> clear on battery timer

		if (utility_fail > 0) {
			if (is_debug_mode > 0) {
				Serial.println(F("VIN OK -> utl f = 0"));
			}
			utility_fail = 0;
			CHARGE_ON();
			on_battery_start_time = 0;
			on_battery_time_mins = 0;
		}
	} // Source




	// Source ok
	if (utility_fail == 0) {

		// On startup delay ?
		if (output_state == OUTPUT_STATE_ON_DELAY) {
			if ((millis() - startup_start_time) / 1000 > startup_delay_secs) {
				// Delay done -> startup
				if (is_debug_mode > 0) Serial.println(F("=> START"));
				do_startup();
				delay(200);
			}
		}
		// Shut down
		if (output_state == OUTPUT_STATE_OFF) {
			// Start after normal delay
			output_state = OUTPUT_STATE_ON_DELAY;
			startup_start_time = millis();
			if (is_debug_mode > 0) Serial.println(F("=> START DLY"));
		}
	} else {
		// Source off

		// Shut down or startup delay -> shut down and save battery
		// Next startup when source is back on
		if ((output_state == OUTPUT_STATE_OFF) || (output_state == OUTPUT_STATE_ON_DELAY)) {
			if (is_debug_mode > 0) Serial.println(F("UTL F + SHDN|DLY -> B OFF"));
			output_state = OUTPUT_STATE_OFF;
			BATTERY_OFF();
			delay(1000);
		}

	}


	// Shutdown in progress, does not depend on source
	if (shutdown_active > 0) {
		if ((millis() - shutdown_start_time) / 1000 > shutdown_delay_secs) {
			if (is_debug_mode > 0) Serial.println(F("=> SHDN"));
			do_shutdown();
			delay(100);
		}
	}




	// Battery connected, check
	//if ((battery_on == 1) && (battery_connected == 1)) {
	if (battery_on == 1) {

		// Too low ?
		if (battery_voltage < battery_bad_voltage) {
			// Voltage < bad => battery is dead if long enough time spent
			if (test_in_progress > 0) {
				// Too low during test -> battery dead & fail
				if (fan_on_test > 0) {
					fan_on_test = 0;
					fan_pwm = set_fan_pwm(fan_min_pwm, 102);
				}
				stop_test();
				CHARGE_OFF();
				BATTERY_OFF();
				battery_low = 1;
				battery_bad = 1;
				battery_fail = 1;
				ups_fail = 1;
				if (is_debug_mode > 0) {
					Serial.println(F("in test VB B -> stop test + fail"));
				}
			} else {
				// During normal operation (not during test)
				if (battery_bad == 0) {
					battery_low = 1;
					battery_bad = 1;
					ups_fail = 1;
					battery_bad_start_time = millis();	// Save start timestamp
					// NOTE: mark battery bad after delay, not on first measurement
					if (is_debug_mode > 0) {
						Serial.println(F("VB B -> bad"));
					}
				} else {
					// Battery too low duration
					battery_bad_time_mins = (millis() - battery_bad_start_time) / 60000;

					if (battery_bad_time_mins > battery_max_bad_mins) {
						// Battery too low too long -> dead
						// Stop charge and disconnect battery
						battery_fail = 1;
						ups_fail = 1;
						CHARGE_OFF();
						BATTERY_OFF();
						if (is_debug_mode > 0) {
							Serial.println(F("VB B time -> fail"));
						}
					}

				}

			}
		}

		// 7.1. Battery low
		else if (battery_voltage < battery_low_voltage) {
			// Voltage between bad ... low -> battery is dead if too long

			// Voltage was < bad and rise to bad ... low -> remove bad flag
			if (battery_bad == 1) {
				battery_bad = 0;
			}

			if (test_in_progress > 0) {
				// Stop test if running. Do not mark bad, leave connected
				stop_test();
				battery_low = 1;
				if (is_debug_mode > 0) {
					Serial.println(F("in test VB L => stop test + low"));
				}
			} else {
				// During normal operation (not during test)
				if (battery_low == 0) {
					battery_low = 1;
					battery_low_start_time = millis();
					if (is_debug_mode > 0) {
						Serial.println(F("VB L -> low"));
					}
				} else {
					// Battery low duration
					battery_low_time_mins = (millis() - battery_low_start_time) / 60000;

					if (battery_low_time_mins > battery_max_low_mins) {
						// Battery low too long -> dead
						// Stop charge and disconnect battery
						battery_low_time_mins = 0;
						battery_fail = 1;
						ups_fail = 1;
						CHARGE_OFF();
						BATTERY_OFF();
						if (is_debug_mode > 0) {
							Serial.println(F("VB L time -> fail"));
						}
					}
				}

			}
		} else {
			// Battery ok, restore
			if (ups_fail == 1) {
				ups_fail = 0;
			}
			if (battery_fail == 1) {
				battery_fail = 0;
			}

			if ((battery_low == 1) || (battery_bad == 1)) {
				battery_bad = 0;
				battery_bad_start_time = 0;
				battery_bad_time_mins = 0;
				battery_low = 0;
				battery_low_start_time = 0;
				battery_low_time_mins = 0;
				if (is_debug_mode > 0) {
					Serial.println(F("VB OK"));
				}
			}

		}


		// Charge
		if (utility_fail == 0) {
			// Only if source ok

			// Only if not testing
			if (test_in_progress == 0) {

				// Charge check
				// Charge start if current > 200mA

				if (charge_current > CHARGE_CURRENT_START) {
					FAN_ON();
					t = millis() - battery_charge_start_time;

					if (battery_charge_start_time == 0) {
						battery_charge_start_time = millis();
						if (is_debug_mode > 0) {
							Serial.println(F("B chg start"));
						}
					} else {

						//t = millis() - battery_charge_start_time;
						battery_charge_time_mins = t / 60000UL;

						// 5 sec fan full, after that adjust with charge current
						//if ((millis() - battery_charge_start_time) > CHARGE_TIME_ADJUST_FAN) {
						if (t > CHARGE_TIME_ADJUST_FAN) {
							if (fan_on_charge == 1) {
								uint8_t f = fan_min_pwm + (uint8_t)((charge_current / MAX_CHARGE_CURRENT) * (float)(fan_max_pwm - fan_min_pwm));
								if (abs(f - fan_pwm) > 2) {
									if (is_debug_mode > 0) {
										Serial.print(F("B chg -> fan set ")); Serial.println(f);
									}
									fan_pwm = set_fan_pwm(f, 105);
								}
							}

						} else if (t > CHARGE_TIME_START_FAN) {
							// Charge duration > 30sec -> start fan
							if (fan_on_charge == 0) {
								fan_on_charge = 1;
								fan_pwm = set_fan_pwm(fan_max_pwm, 104);
								if (is_debug_mode > 0) {
									Serial.print(F("B chg >30sek -> fan start ")); Serial.println(fan_max_pwm);
								}
							}

						}

					}

				}

				// Charge end when current < 100mA
				else if (charge_current < CHARGE_CURRENT_END) {
					if (battery_charge_start_time > 0) {
						battery_charge_start_time = 0;
						if (is_debug_mode > 0) {
							Serial.println(F("B chg end -> stby"));
						}
						battery_charge_time_mins = 0;
					}
				} else {
					// Charge between 100mA ... 200mA -> stop fan when < 200mA
					if (test_in_progress == 0) {
						// Only if not testing (test controls the fan). Just to be sure
						if (fan_on_charge == 1) {
							fan_on_charge = 0;
							fan_pwm = set_fan_pwm(fan_min_pwm, 106);
							if (is_debug_mode > 0) {
								Serial.println(F("B chg < 200 -> fan min"));
							}
						}

					}
				}


				// Maximum charge time reached ?
				// yes -> battery is dead. Disconnect
				if (battery_charge_time_mins >= battery_max_charge_mins) {
					battery_charge_start_time = 0;
					battery_charge_time_mins = 0;
					ups_fail = 1;
					battery_fail = 1;
					CHARGE_OFF();
					BATTERY_OFF();

					if (is_debug_mode > 0) {
						Serial.println(F("B chg t -> b fail"));
					}

					if (fan_on_charge > 0) {
						fan_on_charge = 0;
						fan_pwm = set_fan_pwm(fan_min_pwm, 107);
						if (is_debug_mode > 0) {
							Serial.println(F("B chg t -> fan min"));
						}
					}

				}


				// Automatic test
				// Start only if not running and battery is ok
				if ((battery_on == 1) && (battery_fail == 0)) {
					// Time to start ?
					if ((millis() - last_long_auto_test_time) > (unsigned long)auto_test_interval_mins * 60000UL) {
						// Start timestamp
						last_long_auto_test_time = millis();
						// Duration = 0 min -> test 30 sec
						if (auto_test_duration_mins == 0) {
							test_run_time_secs = 30;
						} else {
							// Duration >= 1 min
							test_run_time_secs = auto_test_duration_mins * 60;
						}

						if (is_debug_mode > 0) {
							Serial.print(F("auto T start: ")); Serial.println(test_run_time_secs);
						}
						// Run as normal test
						start_test();
					}
				}
			} else {
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

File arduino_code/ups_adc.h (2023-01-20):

/*
 * Name:		dc_ups.ino
 * Created:	2022-02-11
 * Author:	Isto Saarinen
 */


#ifndef _UPS_ADC_h
#define _UPS_ADC_h

#include <avr/io.h>


// ADC channels
#define ADC_V_IN				0
#define ADC_V_BATT				1
#define ADC_V_OUT				2
#define ADC_A_CGH				3
#define ADC_A_OUT				4


// ADC channel select
#define ADC0_BITS		((1 << REFS0) )												// ADC0 select
#define ADC1_BITS		((1 << REFS0) |                             (1 << MUX0))	// ADC1 select
#define ADC2_BITS		((1 << REFS0) |               (1 << MUX1))					// ADC2 select
#define ADC3_BITS		((1 << REFS0) |               (1 << MUX1) | (1 << MUX0))	// ADC3 select
#define ADC4_BITS		((1 << REFS0) | (1 << MUX2))								// ADC4 select
#define ADC5_BITS		((1 << REFS0) | (1 << MUX2)               | (1 << MUX0))	// ADC5 select
#define ADC6_BITS		((1 << REFS0) | (1 << MUX2) | (1 << MUX1))					// ADC6 select
#define ADC7_BITS		((1 << REFS0) | (1 << MUX2) | (1 << MUX1) | (1 << MUX0))	// ADC7 select

#define NOP() __asm__ __volatile__ ("nop\n\t")



void initADC();

uint16_t readADC(uint8_t channel);



#endif

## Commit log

2023-10-11 Update dc_ups.ino
    Fixed error in TL, Tnn commands. Changed fan control.
    [dc_ups.ino]
2023-10-11 Schematic update
